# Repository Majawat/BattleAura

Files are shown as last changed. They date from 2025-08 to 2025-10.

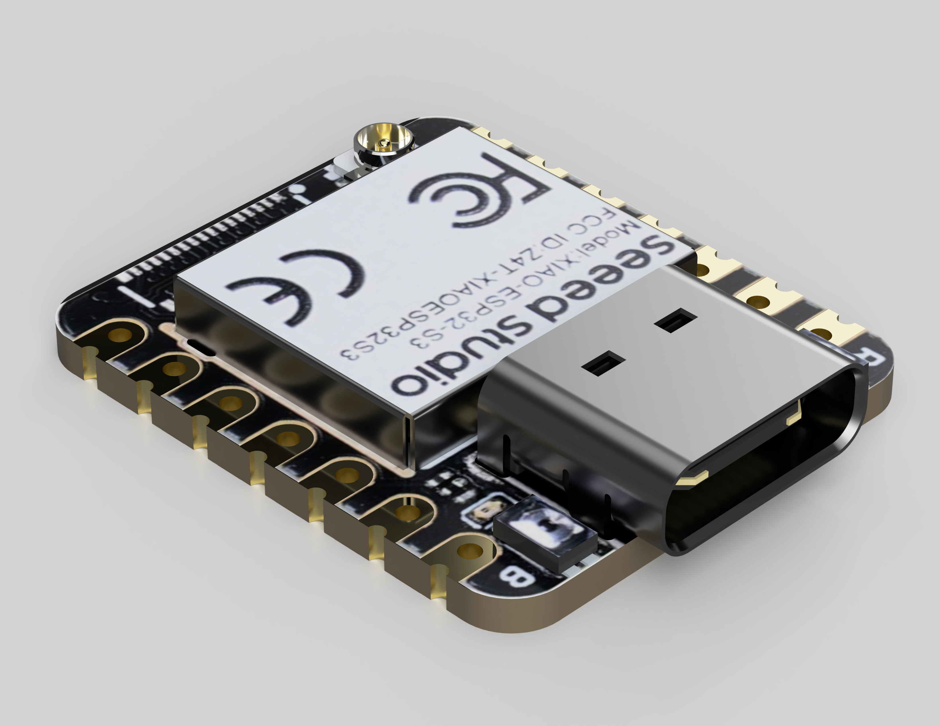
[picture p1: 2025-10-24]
kicad_files/Seeeduino xiao ESP32S3 KiCAD Library/XIAO-ESP32S3.png

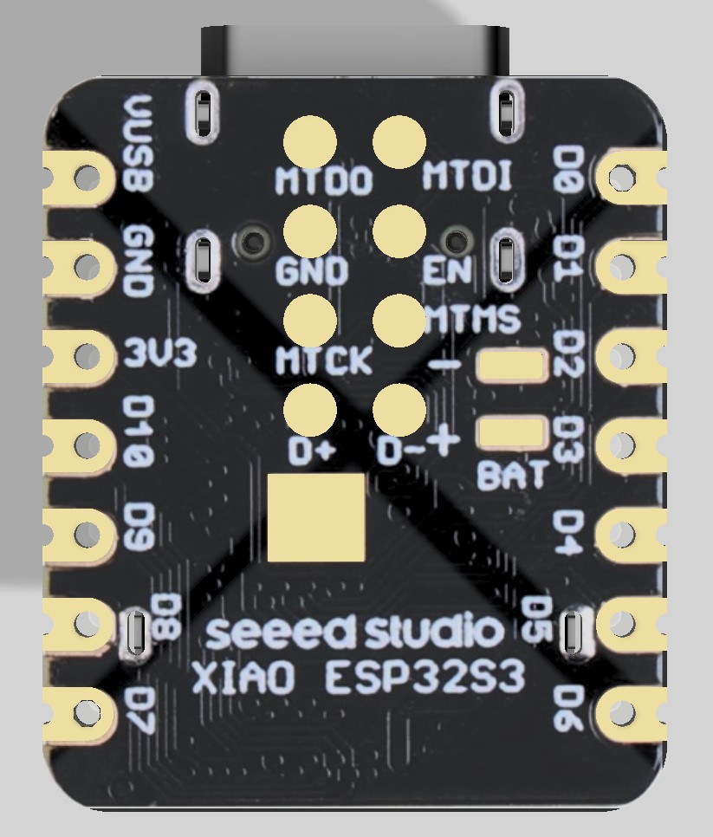
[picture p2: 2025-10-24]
kicad_files/Seeeduino xiao ESP32S3 KiCAD Library/Bottom View.jpg

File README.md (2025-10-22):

# BattleAura
### LED and Sound Controller for wargaming miniatures

## Parts

- Seeed Studio Xiao ESP32-S3 dev board
- DFRobot DFPlayer Mini
- microSD card
- LEDs (single LEDs and WS2812B)
- Speaker (8ohm)
- 14500 Battery

### Wiring Notes

- ESP32 GPIO43 (D6/TX) -> DFPlayer RX
- ESP32 GPIO44 (D7/RX) -> DFPlayer TX
- GPIO 1-9 pins to LEDs+, GND
- Speaker +/1 to DFPlayer
- Battery direct to ESP32-S3 battery terminals, WS2812B, and DFPlayer

## LEDS

### LED Pin assignment

- D0: Candle Fibers 1 - 3mm warm white, 3v
- D1: Candle Fibers 2 - 3mm warm white, 3v
- D2: Candle Fibers 3 - 3mm warm white, 3v
- D3: Console screen - WS2812B RGB, 5v
- D4: Machine Gun - Nano (1.6mm) warm white, 3v
- D5: Flamethrower - Nano (1.6mm) warm white, 3v
- D8: Engine stack 1 - Chip (3.2mm) warm white, 3v
- D9: Engine stack 2 - Chip (3.2mm) warm white, 3v
- D10: Brazier - Chip (3.2mm) warm white, 3v

## Audio files assignments

- 0001 - Tank engine idle 1
- 0002 - Tank engine idle 2
- 0003 - Machine gun fire
- 0004 - Flamethrower
- 0005 - Taking hits
- 0006 - Engine revving
- 0007 - Destroyed
- 0008 - Rocket Launcher
- 0009 - Killed other unit

 ### Audacity settings
  - Track > Mix > Mix stero down to Mono
  - Track > Resample > 22050 Hz
  - Effect > Normalize > -1dB
  - Export as MP3

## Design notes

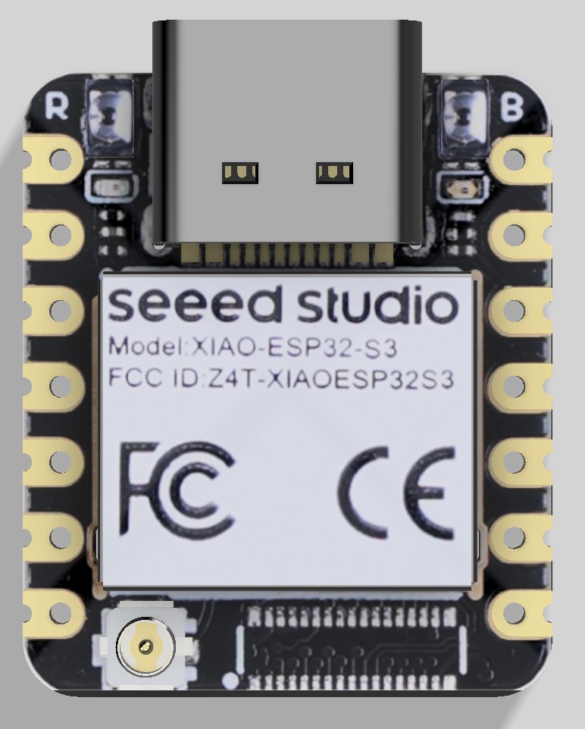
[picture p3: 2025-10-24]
kicad_files/Seeeduino xiao ESP32S3 KiCAD Library/Top view.jpg

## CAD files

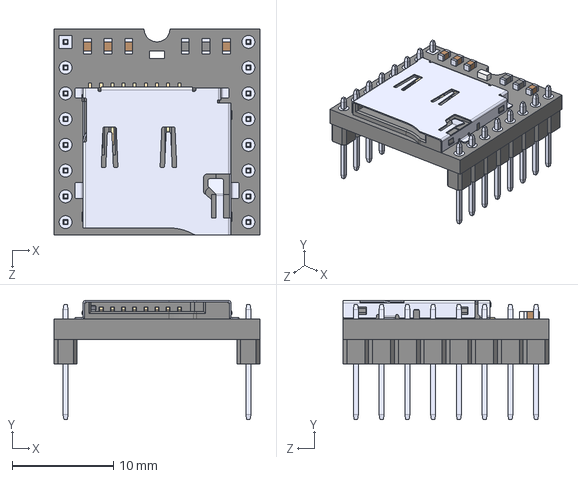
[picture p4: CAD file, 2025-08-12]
kicad_files/DFR0299/DFR0299.step
20.3 x 11.8 x 20.3 mm

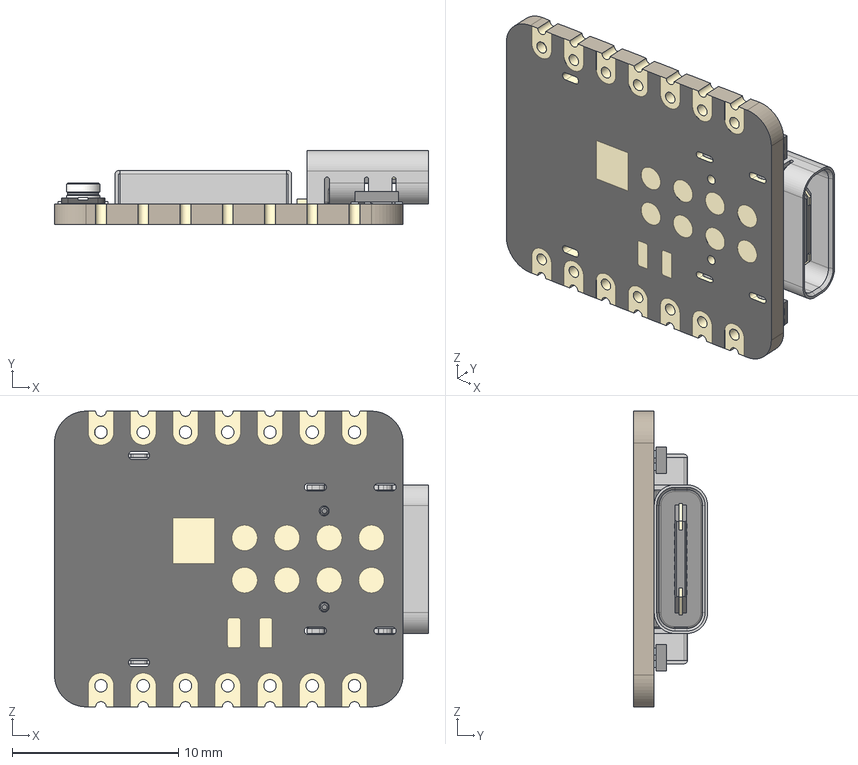
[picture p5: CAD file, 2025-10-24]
kicad_files/Seeeduino xiao ESP32S3 KiCAD Library/XIAO-ESP32S3 v2.step
22.5 x 4.46 x 17.8 mm
BOSS-EXTRUDE14_8_
BOSS-EXTRUDE7_4_
BOSS-EXTRUDE7_3_
BOSS-EXTRUDE14_4_
BOSS-EXTRUDE14_2_
BOSS-EXTRUDE14_11_
BOSS-EXTRUDE7_7_
BOSS-EXTRUDE14_9_
BOSS-EXTRUDE14_3_
BOSS-EXTRUDE14_7_
MIRROR2
BOSS-EXTRUDE14_5_
BOSS-EXTRUDE14_12_
BOSS-EXTRUDE7_8_
BOSS-EXTRUDE7_1_
BOSS-EXTRUDE14_10_
BOSS-EXTRUDE7_9_
BOSS-EXTRUDE14_6_
BOSS-EXTRUDE14_1_
BOSS-EXTRUDE7_6_
BOSS-EXTRUDE7_2_
CUT-EXTRUDE5
BOSS-EXTRUDE7_5_
Shield
Pins x 2
U.FL-R-SMT-1_10_ v1

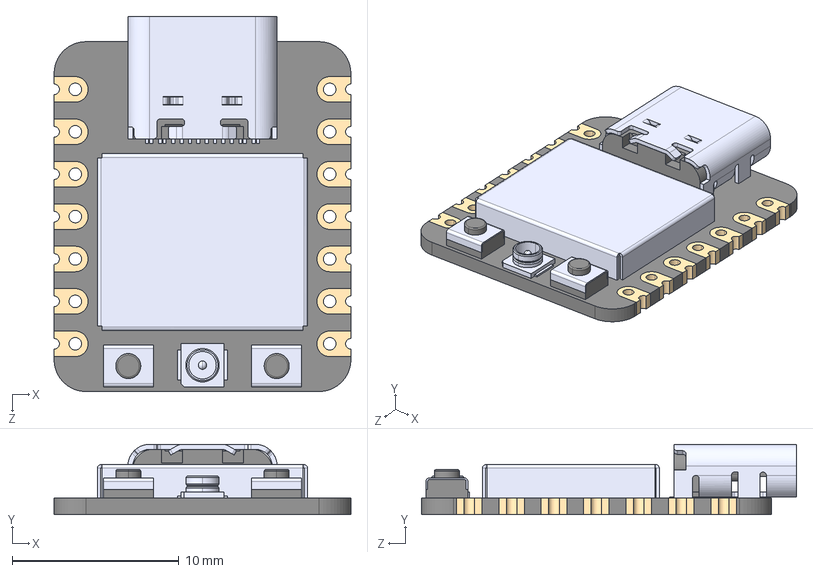
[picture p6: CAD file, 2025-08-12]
kicad_files/Seeeduino xiao ESP32C3 KiCAD Library/113991054.step
17.8 x 4.21 x 22.5 mm

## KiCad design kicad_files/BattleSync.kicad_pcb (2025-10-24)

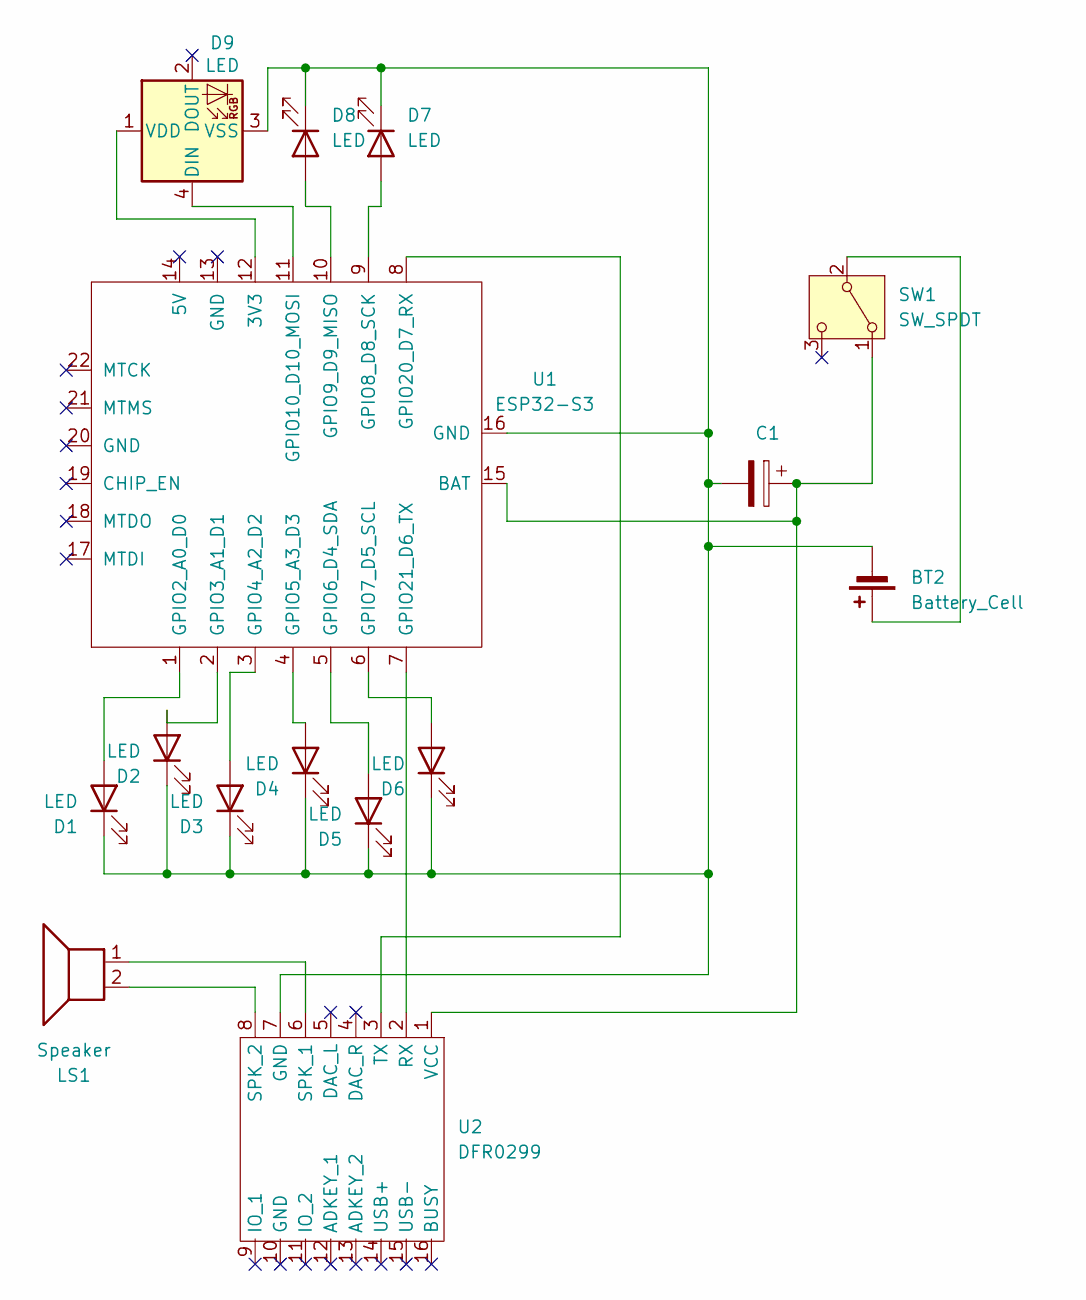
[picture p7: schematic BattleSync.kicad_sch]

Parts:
BT2: Battery_Cell; JST_PH_B2B-PH-K_1x02_P2.00mm_Vertical
C1: C_Polarized; CP_Radial_D4.0mm_P2.00mm
D1, D2, D3, D4, D5, D6, D7, D8: LED; SolderWire-0.1sqmm_1x02_P3.6mm_D0.4mm_OD1mm
D9: LED; SolderWire-0.1sqmm_1x03_P3.6mm_D0.4mm_OD1mm
LS1: Speaker; JST_PH_B2B-PH-K_1x02_P2.00mm_Vertical
SW1: SW_SPDT; SolderWire-0.1sqmm_1x02_P3.6mm_D0.4mm_OD1mm
U1: ESP32-S3; MCU_Seeed_ESP32C3; PARTREV 23/05/2022
U2: DFR0299; MODULE_DFR0299

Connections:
unnamed: BT2.1 (+), SW1.2 (B)
unnamed: BT2.2 (-), C1.2, D1.1 (K), D2.1 (K), D3.1 (K), D4.1 (K), D5.1 (K), D6.1 (K), D7.1 (K), D8.1 (K), D9.3 (VSS), U1.16 (GND), U2.7 (GND)
unnamed: D1.2 (A), U1.1 (GPIO2_A0_D0)
unnamed: D2.2 (A), U1.2 (GPIO3_A1_D1)
unnamed: D3.2 (A), U1.3 (GPIO4_A2_D2)
unnamed: D4.2 (A), U1.4 (GPIO5_A3_D3)
unnamed: D5.2 (A), U1.5 (GPIO6_D4_SDA)
unnamed: D6.2 (A), U1.6 (GPIO7_D5_SCL)
unnamed: D7.2 (A), U1.9 (GPIO8_D8_SCK)
unnamed: D8.2 (A), U1.10 (GPIO9_D9_MISO)
unnamed: D9.4 (VDD), U1.11 (GPIO10_D10_MOSI)
unnamed: D9.1 (DIN), U1.12 (3V3)
unnamed: C1.1, SW1.1 (A), U1.15 (MTDI), U2.1 (VCC)
unnamed: U1.8 (GPIO20_D7_RX), U2.3 (TX)
unnamed: U1.7 (GPIO21_D6_TX), U2.2 (RX)
unnamed: LS1.1, U2.6 (SPK_1)
unnamed: LS1.2, U2.8 (SPK_2)

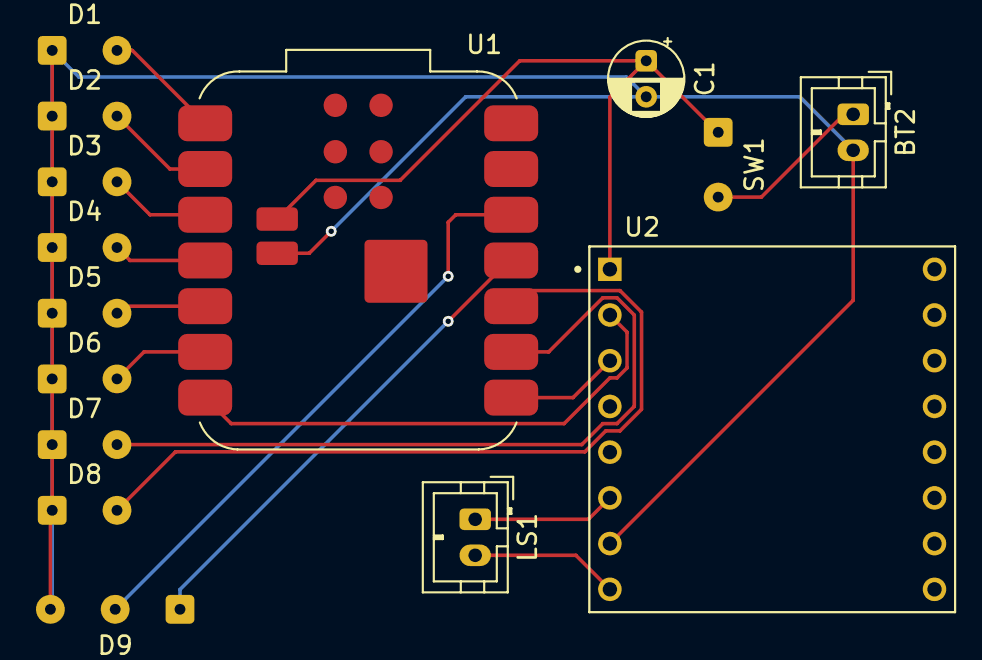
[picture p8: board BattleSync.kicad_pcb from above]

Board: 2 copper layers, 15 parts (0 on the bottom side), 17 nets.

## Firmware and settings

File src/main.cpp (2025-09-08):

#include <Arduino.h>
#include "config/Configuration.h"
#include "hardware/LedController.h"
#include "web/WebServer.h"
#include "vfx/VFXManager.h"
#include "audio/AudioController.h"

using namespace BattleAura;

// Global instances
Configuration BattleAura::config;
LedController ledController;
AudioController audioController(config);
VFXManager vfxManager(ledController, audioController, config);
WebServer webServer(config, ledController, vfxManager, audioController);

void setup() {
    Serial.begin(115200);
    delay(6000);
    Serial.println("\n=== BattleAura v2.4.0-wifi-config - Network Configuration ===");
    
    // Initialize configuration
    Serial.println("Initializing configuration...");
    if (!config.begin()) {
        Serial.println("ERROR: Configuration failed to initialize!");
        return;
    }
    
    // Initialize LED controller
    Serial.println("Initializing LED controller...");
    if (!ledController.begin()) {
        Serial.println("ERROR: LED controller failed to initialize!");
        return;
    }
    
    // Add zones from configuration to LED controller
    auto zones = config.getAllZones();
    Serial.printf("Adding %d zones to LED controller...\n", zones.size());
    for (Zone* zone : zones) {
        ledController.addZone(*zone);
    }
    
    // Initialize web server
    Serial.println("Initializing web server...");
    if (!webServer.begin()) {
        Serial.println("ERROR: Web server failed to initialize!");
        return;
    }
    
    // Initialize VFXManager
    Serial.println("Initializing VFXManager...");
    if (!vfxManager.begin()) {
        Serial.println("ERROR: VFXManager failed to initialize!");
        return;
    }
    
    // Initialize AudioController
    Serial.println("Initializing AudioController...");
    if (!audioController.begin()) {
        Serial.println("WARNING: AudioController failed to initialize (audio will be disabled)");
    }
    
    // Print status
    config.printStatus();
    ledController.printStatus();
    webServer.printStatus();
    vfxManager.printStatus();
    
    Serial.println("\n=== Phase 2 System Ready ===");
    Serial.println("- Full VFX library with priority system active");
    Serial.println("- Mixed PWM and RGB LED support via FastLED");
    Serial.println("- Ambient VFX running automatically");
    Serial.println("- Web interface available for remote control");
    Serial.println("- OTA firmware updates available via web interface");
    Serial.printf("- Access at: http://%s\n", webServer.getIPAddress().c_str());
}

void loop() {
    // Handle web server and OTA
    webServer.handle();
    
    // Update all VFX via VFXManager
    vfxManager.update();
    
    // Apply LED changes to hardware
    ledController.update();
    
    // Update audio controller
    audioController.update();
    
    // Print status every 15 seconds
    static uint32_t lastPrint = 0;
    if (millis() - lastPrint >= 15000) {
        lastPrint = millis();
        Serial.printf("Status: VFX Active | WiFi: %s | IP: %s\n",
                     webServer.isWiFiConnected() ? "Connected" : "AP Mode",
                     webServer.getIPAddress().c_str());
        vfxManager.printStatus();
    }
}

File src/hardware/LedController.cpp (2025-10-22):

#include "LedController.h"

namespace BattleAura {

LedController::LedController() {
    // Reserve space to prevent vector reallocation which breaks WS2812B leds pointers
    zones.reserve(12); // ESP32-S3 supports max 11 GPIO pins for zones (1-9, 43-44)
}

LedController::~LedController() {
    // Destructor - cleanup if needed
}

bool LedController::begin() {
    Serial.println("LedController: Initializing...");
    
    // Initialize any hardware-specific settings here
    // For now, just return success
    
    Serial.println("LedController: Ready");
    return true;
}

void LedController::addZone(const Zone& zone) {
    // Check if zone already exists
    if (findZone(zone.id) != nullptr) {
        Serial.printf("LedController: Zone %d already exists, updating\n", zone.id);
        removeZone(zone.id);
    }
    
    // Support both PWM and WS2812B zones in Phase 2
    if (zone.type != ZoneType::PWM && zone.type != ZoneType::WS2812B) {
        Serial.printf("LedController: Zone %d has unsupported type\n", zone.id);
        return;
    }
    
    // Validate GPIO
    if (!zone.enabled) {
        Serial.printf("LedController: Zone %d is disabled, skipping\n", zone.id);
        return;
    }
    
    // Add to zones list first
    zones.emplace_back(zone);
    
    // Setup hardware based on zone type
    bool setupSuccess = false;
    if (zone.type == ZoneType::PWM) {
        setupSuccess = setupPWM(zones.back());
        if (setupSuccess) {
            Serial.printf("LedController: Added PWM zone %d on GPIO %d\n", zone.id, zone.gpio);
        }
    } else if (zone.type == ZoneType::WS2812B) {
        setupSuccess = setupWS2812B(zones.back());
        if (setupSuccess) {
            Serial.printf("LedController: Added WS2812B zone %d on GPIO %d (%d LEDs)\n", 
                         zone.id, zone.gpio, zone.ledCount);
        }
    }
    
    if (!setupSuccess) {
        Serial.printf("LedController: Failed to setup zone %d on GPIO %d\n", zone.id, zone.gpio);
        zones.pop_back(); // Remove the zone if setup failed
        return;
    }
}

void LedController::removeZone(uint8_t zoneId) {
    zones.erase(
        std::remove_if(zones.begin(), zones.end(),
            [zoneId](const ZoneState& zs) { return zs.zone.id == zoneId; }),
        zones.end()
    );
}

void LedController::setZoneBrightness(uint8_t zoneId, uint8_t brightness) {
    ZoneState* zoneState = findZone(zoneId);
    if (!zoneState) {
        return;
    }
    
    // Scale VFX brightness by user brightness setting
    // brightness parameter is the VFX brightness (0-255)
    // userBrightness is the user's maximum setting (0-255) 
    uint16_t scaledBrightness = (brightness * zoneState->userBrightness) / 255;
    if (scaledBrightness > 255) scaledBrightness = 255;
    
    uint8_t finalBrightness = (uint8_t)scaledBrightness;
    
    if (zoneState->targetBrightness != finalBrightness) {
        zoneState->targetBrightness = finalBrightness;
        zoneState->needsUpdate = true;
    }
}

uint8_t LedController::getZoneBrightness(uint8_t zoneId) const {
    const ZoneState* zoneState = findZone(zoneId);
    return zoneState ? zoneState->currentBrightness : 0;
}

void LedController::setZoneColor(uint8_t zoneId, CRGB color) {
    ZoneState* zoneState = findZone(zoneId);
    if (!zoneState || zoneState->zone.type != ZoneType::WS2812B) {
        return; // Only WS2812B zones support color
    }
    
    if (zoneState->targetColor != color) {
        zoneState->targetColor = color;
        zoneState->needsUpdate = true;
    }
}

void LedController::setZoneColorAndBrightness(uint8_t zoneId, CRGB color, uint8_t brightness) {
    ZoneState* zoneState = findZone(zoneId);
    if (!zoneState) return;
    
    // Scale VFX brightness by user brightness setting
    uint16_t scaledBrightness = (brightness * zoneState->userBrightness) / 255;
    if (scaledBrightness > 255) scaledBrightness = 255;
    
    uint8_t finalBrightness = (uint8_t)scaledBrightness;
    
    bool needsUpdate = false;
    
    if (zoneState->targetBrightness != finalBrightness) {
        zoneState->targetBrightness = finalBrightness;
        needsUpdate = true;
    }
    
    if (zoneState->zone.type == ZoneType::WS2812B && zoneState->targetColor != color) {
        zoneState->targetColor = color;
        needsUpdate = true;
    }
    
    if (needsUpdate) {
        zoneState->needsUpdate = true;
    }
}

CRGB LedController::getZoneColor(uint8_t zoneId) const {
    const ZoneState* zoneState = findZone(zoneId);
    return (zoneState && zoneState->zone.type == ZoneType::WS2812B) ? 
           zoneState->currentColor : CRGB::Black;
}

void LedController::update() {
    for (ZoneState& zoneState : zones) {
        if (zoneState.needsUpdate) {
            // For Phase 2, directly set values - no smooth transitions yet
            zoneState.currentBrightness = zoneState.targetBrightness;
            zoneState.currentColor = zoneState.targetColor;
            
            // Update hardware based on zone type
            if (zoneState.zone.type == ZoneType::PWM) {
                updatePWM(zoneState.pwmChannel, zoneState.currentBrightness, zoneState.zone.brightness);
            } else if (zoneState.zone.type == ZoneType::WS2812B) {
                updateWS2812B(zoneState);
            }
            
            zoneState.needsUpdate = false;
        }
    }
    
    // Update FastLED for all WS2812B changes
    FastLED.show();
}

bool LedController::isZoneConfigured(uint8_t zoneId) const {
    return findZone(zoneId) != nullptr;
}

void LedController::printStatus() const {
    Serial.println("=== LedController Status ===");
    Serial.printf("Configured zones: %d\n", zones.size());
    
    for (const ZoneState& zoneState : zones) {
        const char* typeStr = (zoneState.zone.type == ZoneType::PWM) ? "PWM" : "WS2812B";
        Serial.printf("  Zone %d: GPIO %d, Type: %s", 
                     zoneState.zone.id, zoneState.zone.gpio, typeStr);
        
        if (zoneState.zone.type == ZoneType::PWM) {
            Serial.printf(", PWM Ch: %d", zoneState.pwmChannel);
        } else {
            Serial.printf(", LEDs: %d, Color: R%d G%d B%d", 
                         zoneState.zone.ledCount, 
                         zoneState.currentColor.r, 
                         zoneState.currentColor.g, 
                         zoneState.currentColor.b);
        }
        
        Serial.printf(", Brightness: %d/%d/%d (current/target/max)\n",
                     zoneState.currentBrightness,
                     zoneState.targetBrightness,
                     zoneState.zone.brightness);
    }
}

// Private methods
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

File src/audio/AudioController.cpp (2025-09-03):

#include "AudioController.h"

namespace BattleAura {

AudioController::AudioController(Configuration& config) 
    : config(config), audioSerial(nullptr), currentStatus(AudioStatus::STOPPED),
      currentTrack(0), currentVolume(15), playStartTime(0), audioAvailable(false),
      lastStatusCheck(0), lastRetryAttempt(0), enableRetries(true) {
}

bool AudioController::begin() {
    Serial.println("AudioController: Initializing...");
    
    const auto& deviceConfig = config.getDeviceConfig();
    
    // Skip initialization if audio is disabled
    if (!deviceConfig.audioEnabled) {
        Serial.println("AudioController: Audio disabled in configuration");
        audioAvailable = false;
        enableRetries = false;  // Don't retry if disabled in config
        return true; // Return success but mark as unavailable
    }
    
    return retryInitialization();
}

bool AudioController::play(uint16_t fileNumber, bool loop) {
    if (!audioAvailable) {
        Serial.println("AudioController: Audio not available");
        return false;
    }
    
    if (fileNumber == 0) {
        Serial.println("AudioController: Invalid file number 0");
        return false;
    }
    
    Serial.printf("AudioController: Playing file %d %s\n", fileNumber, loop ? "(loop)" : "");
    
    if (loop) {
        dfPlayer.loop(fileNumber);
    } else {
        dfPlayer.play(fileNumber);
    }
    
    currentTrack = fileNumber;
    currentStatus = AudioStatus::PLAYING;
    playStartTime = millis();
    
    return true;
}

bool AudioController::playTrack(const String& trackName) {
    const AudioTrack* track = config.getAudioTrack(trackName);
    if (!track) {
        Serial.printf("AudioController: Track '%s' not found\n", trackName.c_str());
        return false;
    }
    
    return play(track->fileNumber, track->isLoop);
}

bool AudioController::stop() {
    if (!audioAvailable) return false;
    
    dfPlayer.stop();
    currentStatus = AudioStatus::STOPPED;
    currentTrack = 0;
    playStartTime = 0;
    
    Serial.println("AudioController: Stopped");
    return true;
}

bool AudioController::pause() {
    if (!audioAvailable) return false;
    
    dfPlayer.pause();
    currentStatus = AudioStatus::PAUSED;
    
    Serial.println("AudioController: Paused");
    return true;
}

bool AudioController::resume() {
    if (!audioAvailable) return false;
    
    dfPlayer.start();
    currentStatus = AudioStatus::PLAYING;
    
    Serial.println("AudioController: Resumed");
    return true;
}

bool AudioController::next() {
    if (!audioAvailable) return false;
    
    dfPlayer.next();
    updateCurrentStatus();
    
    Serial.println("AudioController: Next track");
    return true;
}

bool AudioController::previous() {
    if (!audioAvailable) return false;
    
    dfPlayer.previous();
    updateCurrentStatus();
    
    Serial.println("AudioController: Previous track");
    return true;
}

bool AudioController::setVolume(uint8_t volume) {
    if (!audioAvailable) return false;
    
    if (volume > 30) volume = 30;
    
    dfPlayer.volume(volume);
    currentVolume = volume;
    
    Serial.printf("AudioController: Volume set to %d\n", volume);
    return true;
}

uint8_t AudioController::getVolume() const {
    return currentVolume;
}

bool AudioController::volumeUp() {
    if (currentVolume < 30) {
        return setVolume(currentVolume + 1);
    }
    return true;
}

bool AudioController::volumeDown() {
    if (currentVolume > 0) {
        return setVolume(currentVolume - 1);
    }
    return true;
}

AudioStatus AudioController::getStatus() const {
    return currentStatus;
}

uint16_t AudioController::getCurrentTrack() const {
    return currentTrack;
}

bool AudioController::isPlaying() const {
    return currentStatus == AudioStatus::PLAYING;
}

bool AudioController::isAvailable() const {
    return audioAvailable;
}

bool AudioController::addTrack(const AudioTrack& track) {
    return config.addAudioTrack(track);
}

bool AudioController::removeTrack(uint16_t fileNumber) {
    return config.removeAudioTrack(fileNumber);
}

AudioTrack* AudioController::getTrack(uint16_t fileNumber) {
    return config.getAudioTrack(fileNumber);
}

AudioTrack* AudioController::getTrack(const String& trackName) {
    return config.getAudioTrack(trackName);
}

std::vector<AudioTrack*> AudioController::getAllTracks() {
    return config.getAllAudioTracks();
}

bool AudioController::testTrack(uint16_t fileNumber) {
    if (!audioAvailable) return false;
    
    Serial.printf("AudioController: Testing track %d\n", fileNumber);
    
    // Stop any current playback
    stop();
    delay(100);
    
    // Play track for 3 seconds
    if (play(fileNumber, false)) {
        delay(3000);
        stop();
        return true;
    }
    
    return false;
}

void AudioController::printStatus() const {
    Serial.println("=== AudioController Status ===");
    Serial.printf("Available: %s\n", audioAvailable ? "Yes" : "No");
    Serial.printf("Status: ");
    
    switch (currentStatus) {
        case AudioStatus::STOPPED: Serial.println("Stopped"); break;
        case AudioStatus::PLAYING: Serial.println("Playing"); break;
        case AudioStatus::PAUSED: Serial.println("Paused"); break;
        case AudioStatus::ERROR: Serial.println("Error"); break;
    }
    
    Serial.printf("Current Track: %d\n", currentTrack);
    Serial.printf("Volume: %d/30\n", currentVolume);
    
    auto tracks = config.getAllAudioTracks();
    Serial.printf("Available Tracks: %d\n", tracks.size());
    
    if (!tracks.empty()) {
        Serial.println("Track List:");
        for (const AudioTrack* track : tracks) {
            Serial.printf("  %d: %s %s\n", track->fileNumber, track->description.c_str(),
                         track->isLoop ? "(loop)" : "");
        }
    }
}

uint16_t AudioController::getAvailableTrackCount() const {
    return config.getAllAudioTracks().size();
}

void AudioController::update() {
    uint32_t currentTime = millis();
    
    // If audio is not available but retries are enabled, attempt periodic reconnection
    if (!audioAvailable && enableRetries) {
        // Retry every 30 seconds
        if (currentTime - lastRetryAttempt >= 30000) {
            Serial.println("AudioController: Attempting periodic retry...");
            retryInitialization();
            lastRetryAttempt = currentTime;
        }
        return;
    }
    
    // If audio is available, periodically check DFPlayer status
    if (audioAvailable && currentTime - lastStatusCheck >= STATUS_CHECK_INTERVAL) {
        checkPlayerStatus();
        lastStatusCheck = currentTime;
    }
}

// Private methods

bool AudioController::initializeHardware() {
    // Hardware initialization is done in begin()
    return audioAvailable;
}
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

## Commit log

2025-08-06 Add project structure and initial implementation for DFPlayer with candle flicker effect
    - Created README files for include, lib, and test directories to provide project structure and usage instructions.
    - Added platformio.ini configuration for the Seeed Xiao ESP32C3 board with necessary library dependencies.
    - Implemented main application logic in src/main.cpp to control DFPlayer and simulate candle flicker using LEDs.
    - Included detailed error handling and status reporting for DFPlayer operations.
    [main.cpp]
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2025-08-12 add WiFi captive portal and OTA firmware updates
    - Add WiFiManager for easy WiFi configuration via captive portal
    - Implement web-based OTA firmware upload at hostname.local
    - Add semantic versioning display on web interface (v0.7.0)
    - Improve candle flicker effect with time-based base intensity changes
    - Fix duplicate LED6 definition, rename variables for clarity
    - Add mDNS support for friendly hostname access
    [main.cpp]
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2025-08-13 fix DFPlayer status detection by testing actual communication
    Previously, dfPlayer.begin() would return true even when the TX wire was
    disconnected, showing "Connected" status on the web interface incorrectly.
    Changes:
    - Test bidirectional communication by setting and reading volume during init
    - Add periodic status checking every 10 seconds with readVolume()
    - Properly detect connection loss and reconnection
    - Update status messages to be more descriptive (No Response, Connection Lost)
    - Add automatic reconnection and idle sound restart when connection restored
    This ensures the web interface accurately reflects the actual DFPlayer
    communication status, preventing false "Connected" reports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
    [main.cpp]
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2025-08-13 complete DFPlayer module separation and fix compilation errors
    Fixed build errors by properly organizing DFPlayer state variables:
    DFPlayer Module Changes:
    - Moved all DFPlayer state variables from main.cpp to dfplayer.cpp
    - Added extern declarations in dfplayer.h for cross-module access
    - Variables: dfPlayerConnected, dfPlayerPlaying, currentTrack, dfPlayerStatus, lastStatusCheck
    - printDetail function now has access to state variables for status updates
    Code Organization:
    - Complete separation of DFPlayer functionality from main program
    - Proper module encapsulation with extern variable pattern
    - Resolved compilation errors: 'dfPlayerPlaying' and 'dfPlayerStatus' not declared
    Web Interf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
    [main.cpp]
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2025-08-13 add GitHub Actions workflow for automated firmware builds
    - Add build.yml workflow that triggers on version tags
    - Only deploy clean versions (v1.2.3), skip pre-release (v1.2.3-alpha)
    - Workflow builds firmware and shows size info
    - Sets up foundation for automated deployment to battlesync.me
    - Update version to 0.16.2 for GitHub Actions testing
    Co-Authored-By: Claude <noreply@anthropic.com>
    [main.cpp]
2025-08-13 fix GitHub Actions: update upload-artifact to v4
    - Replace deprecated v3 with v4 to fix workflow failure
    - Update version to 0.16.5
    [main.cpp]
2025-08-13 fix artifact filename typo: battlearua -> battleaura
    - Correct spelling in GitHub Actions artifact name
    - Update version to 0.16.6
    [main.cpp]
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2025-08-13 fix missing ArduinoJson library dependency
    - Add bblanchon/ArduinoJson@^7.0.4 to platformio.ini
    - Required for OTA update JSON parsing functionality
    - Update version to 0.17.1
    [main.cpp]
2025-08-13 fix ArduinoJson v7 API compatibility issues
    - Replace deprecated DynamicJsonDocument with JsonDocument
    - Fix string concatenation issues with F() macros
    - Break complex string concatenations into separate operations
    - Update version to 0.17.2
    [main.cpp]
2025-08-14 test upload to battlesync.me with proper API endpoints
    - Endpoints already correctly configured for new API structure
    - GitHub Actions: POST /api/battleaura/firmware/upload
    - Device check: GET /api/battleaura/firmware/latest
    - Add proper HTTP status code checking to workflow
    - Update version to 0.17.3 for testing
    [main.cpp]
2025-08-14 fix GitHub Actions HTTP status code parsing
    - Separate HTTP status code from JSON response body
    - Use --output /dev/null to discard response body
    - Only capture status code for success/failure checking
    - Update version to 0.17.4
    [main.cpp]
2025-08-14 improve weapon effect UX - remove redirect pages
    - Replace 'effect triggered' pages with HTTP 302 redirects
    - Users stay on main interface after firing weapons
    - Better for rapid testing and multiple effects
    - Update version to 0.17.5
    [main.cpp]
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2025-08-14 fix engine rev effect - auto-resume idle audio
    - Add track 6 (AUDIO_ENGINE_REV) to DFPlayer callback
    - Engine rev now properly resumes idle audio when finished
    - Update PlayFinished callback to handle all battle effects
    - Update version to 0.18.1
    [main.cpp]
2025-08-14 redesign web interface and fix emoji display issues
    - Remove all emojis that display as corrupted characters on ESP32
    - Reorganize page layout: Battle Effects first, System Status compact
    - Move firmware info into Firmware Management section
    - Add DFPlayer reconnect button when disconnected
    - Improve page hierarchy and user experience
    - Update version to 0.19.0
    [main.cpp]
2025-08-14 v0.19.1: Add auto-reconnect after firmware updates
    - Add 30-second countdown timer after update initiation
    - Automatic redirect to current host after device reboot
    - Manual reconnect link as backup option
    - Improved user experience for OTA updates
    [main.cpp]
2025-08-14 v0.19.2: Simplify web interface styling to save flash memory
    - Reduce CSS from ~25 lines to ~7 lines with minified styles
    - Remove detailed theming, transitions, and verbose properties
    - Use shorthand CSS notation (color:#5af instead of color:#58a6ff)
    - Consolidate styling across all web pages
    - Maintain dark theme with basic functionality
    - Significant flash memory savings for additional features
    [main.cpp]
2025-08-14 v0.19.3: Add device reboot button to web interface
    - Add /reboot endpoint and handleReboot() function
    - Include reboot button in System Controls section
    - Show confirmation dialog before rebooting
    - Display reboot page with auto-redirect after 10 seconds
    - Useful for troubleshooting and remote device management
    [main.cpp]
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2025-08-14 v0.21.0: Add comprehensive battle effects system
    - Taking hits: console alerts, power fluctuation, engine strain
    - Destroyed: progressive system failure with complete shutdown via ESP.deepSleep()
    - Rocket: explosive backlight effect using candles and console
    - Unit kill: victory celebration with synchronized LED flashes
    - All effects synchronized with corresponding audio tracks
    - Web interface with Battle Events section and confirmation dialogs
    - Audio properly stopped before deep sleep shutdown
    [main.cpp]
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2025-08-14 v0.25.0: Universal pin-to-effect configuration system
    - Replaced hardcoded LED assignments with dynamic configuration
    - Added EffectMapping and TriggerMapping structures
    - Implemented runBackgroundEffects() for configurable continuous effects
    - Main loop now runs effects based on deviceConfig instead of hardcoded calls
    - System ready for any device type (tank, beast, etc.) without code changes
    - Foundation for web-based effect configuration interface
    [main.cpp]
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2025-08-22 v0.28.0: Add RGB LED support for D3 console with enhanced battle effects
    - Add Adafruit NeoPixel library dependency for WS2812 RGB LEDs
    - Implement RGB LED support on D3 pin with colorful console effects
    - Add new RGB effect types: rgb_blue, rgb_red, rgb_green, rgb_pulse_blue, rgb_pulse_red
    - Enhanced battle effects with color-coded console alerts:
    * Taking hits: Red warning flashes
    * Destroyed: Random warning colors during system failure
    * Rocket: Bright white explosion with blue afterglow
    * Unit kill: Green success indicators
    - Update web interface to show RGB options for D3 pin
    - Maintain backward compatibility with existing single-color effects
    - RGB effects automatically fall ba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
    [main.cpp]
2025-08-22 v0.29.0: Convert to fully non-blocking operation for responsive web interface
    Major architecture overhaul eliminating 59 blocking delays:
    - Convert all weapon effects to non-blocking state machines
    - Implement sophisticated battle effect state system with multi-phase operations
    - Remove blocking delays from web handlers and main loop
    - Preserve only critical hardware delays (DFPlayer communication)
    - Add concurrent weapon effect support (up to 4 simultaneous)
    - Battle effects now use progressive state machines:
    * Taking hits: Console alerts → power fluctuation → engine strain
    * Destroyed: System failure → progressive dimming → deep sleep
    * Rocket: Explosion backlight → conso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
    [main.cpp]
2025-08-23 v0.31.0: Complete modular configuration system with persistent storage
    Major architectural changes:
    - Replace all hardcoded LED pins (LED1-LED9) with dynamic PinConfig system
    - Add comprehensive SPIFFS/JSON configuration persistence
    - Implement modular pin assignment supporting any D0-D10 configuration
    - Dynamic RGB pin detection replaces hardcoded D3 assumptions
    - Battle effects now use dynamic pin lookups by label
    - Audio track management with proper DFPlayer numbering (0001-0009.mp3)
    - Web interface now uses pins[] array instead of deprecated backgroundEffects[]
    Technical improvements:
    - Add helper functions: getPinByLabel(), getPinByType(), isRGBPin(), getEffectById()
    - Configuration su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
    [main.cpp]
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2025-08-25 v1.0.0: Complete architectural rebuild - Modular configuration-driven system
    BREAKING CHANGES:
    - Complete rewrite from scratch with modular architecture
    - Configuration-driven design (no hardcoded pins)
    - New web interface with real-time WebSocket control
    - Support for both standard LEDs and WS2812B RGB strips
    MAJOR FEATURES:
    * Modular Architecture:
    - ConfigManager: JSON-based configuration with SPIFFS persistence
    - EffectManager: Comprehensive lighting effects engine (9+ effects)
    - AudioManager: DFPlayer Mini integration with error handling
    - Web Interface: Mobile-responsive control with WebSocket + HTTP fallback
    * Configuration System:
    - Pin assignments fully configurable via w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
    [main.cpp]
2025-08-25 v1.0.1: Complete rebuild with solid foundation - Fixed critical startup bugs
    - Removed all broken complex initialization code
    - Started fresh with minimal working foundation
    - Simple, reliable web interface with proper error handling
    MAJOR FIXES:
    * Critical Bug Fixes:
    - Fixed early return in setup() that prevented main loop execution
    - Removed complex SPIFFS dependency that caused crashes
    - Eliminated problematic JSON parsing during startup
    - Fixed memory allocation issues in effects manager
    - Removed blocking WiFi connection attempts
    * Solid Foundation Architecture:
    - Clean startup sequence with comprehensive error handling
    - Simple WebServer instead of com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
    [main.cpp]
2025-08-25 v1.1.0-foundation: Proper modular architecture with best practices
    - Complete separation of concerns with HAL/Core/Web layers
    - Hardware Abstraction Layer (GPIOManager) with ESP32-C3 validation
    - JSON-based configuration system with SPIFFS persistence
    - Professional web interface with separate HTML/CSS/JS files
    - WebServer with RESTful API endpoints and proper error handling
    - Fixed DISABLED enum conflict with ESP32 framework macros
    - Singleton patterns for all manager classes
    - Configuration-driven design with no hardcoded pins
    - Robust initialization sequence with graceful error handling
    - Mobile-responsive frontend with modern JavaScript architecture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
    [main.cpp]
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2025-08-25 Fix ArduinoJson v7 API compatibility and function declarations
    - Replace deprecated containsKey() with is<T>() checks per ArduinoJson v7
    - Fix JsonArray assignment using as<JsonArray>() method
    - Add missing function declarations in main.cpp
    - Resolves compilation errors with modern ArduinoJson library
    These issues stem from library API changes between versions - containsKey()
    was deprecated in favor of type-safe checking methods.
    [main.cpp]
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2025-08-25 v0.1.0-dev: Complete rebuild with minimal working foundation
    BREAKING CHANGE: Complete rewrite from scratch after multiple failed attempts
    - Strip down to absolute essentials: WiFi AP + WebServer only
    - Remove all complex architecture that caused library conflicts
    - Use only built-in ESP32 libraries (WiFi, WebServer)
    - Single main.cpp file with clear, testable functionality
    - Non-blocking loop with millis() timing (no delay())
    - Memory-efficient HTML using F() macros
    - Proper development versioning (v0.x for pre-production)
    This provides a stable foundation for incremental feature addition.
    Previous attempts failed due to overengineering and library conflicts.
    Testing: ESP32 creates "Batt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
    [main.cpp]
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2025-08-25 Fix emoji encoding and favicon 404 errors
    - Add UTF-8 charset meta tag to fix emoji display (🎯 was showing as ðŸŽ¯)
    - Add favicon handler to prevent 404 errors in serial output
    - Improves user experience with proper emoji rendering
    [main.cpp]
2025-08-25 Add OTA (Over-The-Air) firmware update capability
    - Enable ArduinoOTA with hostname "BattleAura" and password "battlesync"
    - Add comprehensive OTA callbacks for progress/error reporting
    - Display OTA connection info on web interface
    - Handle OTA updates in main loop (non-blocking)
    - Version bump to v0.1.1-dev
    Now supports wireless firmware updates via Arduino IDE:
    Tools → Port → Network Port → BattleAura
    [main.cpp]
2025-08-25 Replace Arduino IDE OTA with web-based firmware upload
    - Remove ArduinoOTA dependency in favor of web interface
    - Add /update endpoint with file upload form
    - Handle firmware.bin uploads directly via HTTP
    - Proper PlatformIO workflow: build → upload via web browser
    - Auto-restart after successful update with progress feedback
    - Better integration with VSCode/PlatformIO development cycle
    Upload process:
    1. Run: platformio run
    2. Upload: .pio/build/seeed_xiao_esp32c3/firmware.bin via web
    [main.cpp]
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2025-08-25 Fix web-based OTA firmware upload functionality
    - Separate POST response handler from upload handler properly
    - Use ESP.getFreeSketchSpace() for proper size calculation
    - Add detailed serial logging for debugging upload process
    - Add static error tracking to prevent multiple responses
    - Handle all upload status cases including UPLOAD_FILE_ABORTED
    - Improved error reporting and debugging output
    This should resolve the "Update failed to complete" issue.
    [main.cpp]
2025-08-25 Fix all HTML strings to use F() macro for proper UTF-8 encoding
    - Convert all server.send() strings to use F() macro for flash storage
    - Add proper Content-Type header with UTF-8 charset for HTML responses
    - Fix emoji encoding issues (✅ should now display correctly)
    - Improve memory efficiency by storing strings in flash vs RAM
    - Version bump to v0.2.1-dev
    This resolves emoji display problems and reduces RAM usage by storing
    static strings in abundant flash memory instead of limited RAM.
    [main.cpp]
2025-08-25 Implement Phase 3: Configuration system with SPIFFS storage
    - Add SPIFFS filesystem support with partition configuration
    - Create comprehensive configuration structures (SystemConfig, PinConfig)
    - Implement JSON-based configuration persistence with ArduinoJson v7
    - Support for 8 configurable pins with multiple modes (Digital, PWM, WS2812B, Input)
    - Graceful fallback to defaults if config missing or invalid
    - Dynamic GPIO setup based on configuration vs hardcoded pins
    - Configuration loading/saving with proper error handling
    - Enhanced system info with configuration status
    - Version bump to v0.3.0-dev
    Key features:
    - Pin modes: DISABLED, OUTPUT_DIGITAL, OUTPUT_PWM, OUTPUT_WS2812B, INPUT_DIGI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
    [main.cpp]
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2025-08-25 Implement Phase 5: WiFi station mode with AP fallback and mDNS support
    - Add WiFi station mode with automatic connection to configured networks
    - Implement 15-second timeout for station connections with AP fallback
    - Add mDNS responder for device discovery via hostname.local
    - Use configured device name as AP SSID when available
    - Enhanced system info display showing current WiFi status and connection details
    - Update version to 0.5.0-dev
    - Add comprehensive WiFi connection logging and error reporting
    [main.cpp]
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2025-08-26 Add comprehensive RGB LED testing and debug capabilities
    Features added:
    - RGB LED test endpoints (/rgb/red, /rgb/green, /rgb/blue, /rgb/white, /rgb/off)
    - Rainbow cycling test (/rgb/test) with automatic color transitions
    - Enhanced debug output for LED control and GPIO setup
    - Cross-platform MAX_PINS definitions for all ESP32 variants
    - Detailed serial debugging for pin configuration troubleshooting
    - Fixed MAX_PINS definition missing on ESP32-S3, ESP32-S2, and ESP32 variants
    - Added comprehensive debug logging to handleLedControl() function
    - Added debug logging to setupGPIO() function for configuration verification
    - WS2812B RGB LED support with 10 LEDs per strip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
    [main.cpp]
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2025-08-26 Implement comprehensive RGB LED improvements and brightness controls
    RGB Color Persistence Fix:
    - Fixed RGB colors flashing back to white due to active effects
    - RGB endpoints now automatically stop effects before setting colors
    - /rgb/blue, /rgb/red, etc. now maintain color permanently until changed
    - Added debug logging for effect stopping
    Configurable LED Count:
    - Added ledCount field to PinConfig structure (default: 10 LEDs)
    - NeoPixel strips now use configured LED count instead of hardcoded value
    - Dynamic memory allocation based on actual LED count per strip
    - Configuration saved/loaded from SPIFFS with ledCount persistence
    Brightness Controls:
    - Global brightness: /brightness?value=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
    [main.cpp]
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2025-08-26 Restructure web UI to use SPIFFS data directory
    Major refactoring to improve web UI maintainability and separation of concerns:
    ## Changes Made:
    - **Web UI Separation**: Extracted embedded HTML/CSS/JavaScript strings into separate files
    - **Data Directory**: Created `/data/` directory with clean file structure:
    - `index.html` - Clean HTML structure with proper semantic markup
    - `styles.css` - Comprehensive CSS styling with dark theme and responsive design
    - `app.js` - JavaScript functionality with error handling and user feedback
    - **SPIFFS Integration**: Updated main.cpp to serve static files from SPIFFS
    - **API Enhancement**: Added `/api/status` JSON endpoint for dynamic data
    - **St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
    [main.cpp]
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2025-08-26 Improve web UI usability and add LED count control
    Enhanced the web interface with better user experience and missing functionality:
    ## Web UI Improvements:
    - **0% Brightness**: Added 0% brightness button to complete the range (was 25-100%, now 0-100%)
    - **LED Count Control**: Added quick LED count setting directly on main page
    - **Better UX**: Users no longer need to go to config page for common LED settings
    - **LED Count Endpoint**: Added `/ledcount?value=X` API endpoint for runtime LED count updates
    - **Auto-Reinitialization**: NeoPixel strips automatically reinitialize when count changes
    - **Configuration Persistence**: LED count changes are saved to configuration file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
    [main.cpp]
2025-08-26 Implement proper brightness system with global max and per-pin multipliers
    Major overhaul of brightness control system to address user experience issues:
    ## Version Update:
    - **Version**: Updated to 2.0.0-dev (major architectural changes warrant major version)
    ## Brightness System Redesign:
    - **Global Max Brightness**: System-wide ceiling for all LEDs (0-255)
    - **Per-Pin Brightness**: Individual multipliers relative to global max (0-255)
    - **Calculation**: `actual = (globalMax * pinBrightness) / 255`
    - **Configuration Persistence**: Both global and per-pin brightness saved to SPIFFS
    ## User Experience Improvements:
    - **Global Control**: "Dim everything for stealth" or "Full brightness for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
    [main.cpp]
2025-08-26 Fix core brightness and UI issues
    Critical fixes to address user experience problems:
    ## Fixed RGB Color Brightness Issue:
    - **Root Cause**: RGB endpoints were hardcoded to brightness 255, ignoring global max
    - **Solution**: RGB endpoints now save color to pin config and use calculateActualBrightness()
    - **Result**: RGB colors now respect both global max and per-pin brightness settings
    ## Cleaned Up UI Placement:
    - **Removed**: Misplaced per-pin controls from main page (belongs in config)
    - **Removed**: LED count "quick setting" from main page (belongs per-pin in config)
    - **Fixed**: Main page now focuses on actual gameplay controls, not configuration
    ## Brightness Calculation:
    - RGB endp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
    [main.cpp]
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2025-08-27 Implement type-based effect endpoints and API for modular system
    - Added /api/types endpoint to return configured pin types for dynamic UI
    - Added /effect POST endpoint for type-based effect targeting
    - Added /global POST endpoint for global effects (damage, victory, alert, off)
    - Added mapEffectNameToType helper function with forward declaration
    - Effects now target pin types (Engine, Weapon, Candle) instead of hardcoded pins
    - Support for capabilities-aware effects (RGB vs PWM pin handling)
    - Maintains existing static HTML/JavaScript approach while adding modular backend
    Next: Update existing app.js to use new endpoints for dynamic type-based UI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
    [main.cpp]
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2025-08-28 Implement complete modular type-based effects system v2.2.0
    **Core Features:**
    - ✅ Type-based effect mapping: 13 different effects adapt to pin capabilities (PWM/RGB)
    - ✅ Audio-synchronized effects: Effects duration matches audio file length automatically
    - ✅ Smart duration system: Manual override → audio duration → sensible defaults
    - ✅ Automatic effect expiration: Effects stop when audio ends, ready for priority system
    **Effects Library:**
    - Engine: idle (gentle pulse), rev (aggressive)
    - Weapons: fire (machine gun burst), flamethrower (flickering), rocket (flash+trail)
    - Damage: damage/hit (red flash), explosion (bright fade)
    - Ambient: flicker (candle), pulse, fade, strobe
    -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
    [main.cpp]
2025-08-28 Complete modular smart interface system v2.3.0
    **Major Achievement: Full Modular Vision Realized**
    **🎯 Ambient vs Active Priority System:**
    - ✅ Intelligent effect layering: Temporary effects interrupt ambient, then auto-restore
    - ✅ Smart state management: Never loses ambient context during active effects
    - ✅ Boot sequence: All pins start with configured defaultEffect as ambient background
    - ✅ Synchronized restoration: Perfect timing for group effects and damage sequences
    **🎨 Dynamic UI Generation:**
    - ✅ Type-aware interface: Buttons appear only for configured pin types
    - ✅ Smart categorization: Effects grouped by function (🚗Engine, ⚔️Weapon, 🕯️Candle, 💻Cons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
    [main.cpp]
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
